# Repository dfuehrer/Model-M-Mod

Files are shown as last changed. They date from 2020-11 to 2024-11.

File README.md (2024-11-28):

# keyboard
- Arduino sketch that works ok for windows and menu keys
    - they occasionally miss the release so I'll have to make the code better later
        - or give up and switch to qmk
- used kailh choc brown switches cause theyre low profile to sit on the plastic
    - maybe I should have used a clicky switch since it's not like the tactile switches match the buckling springs in any way
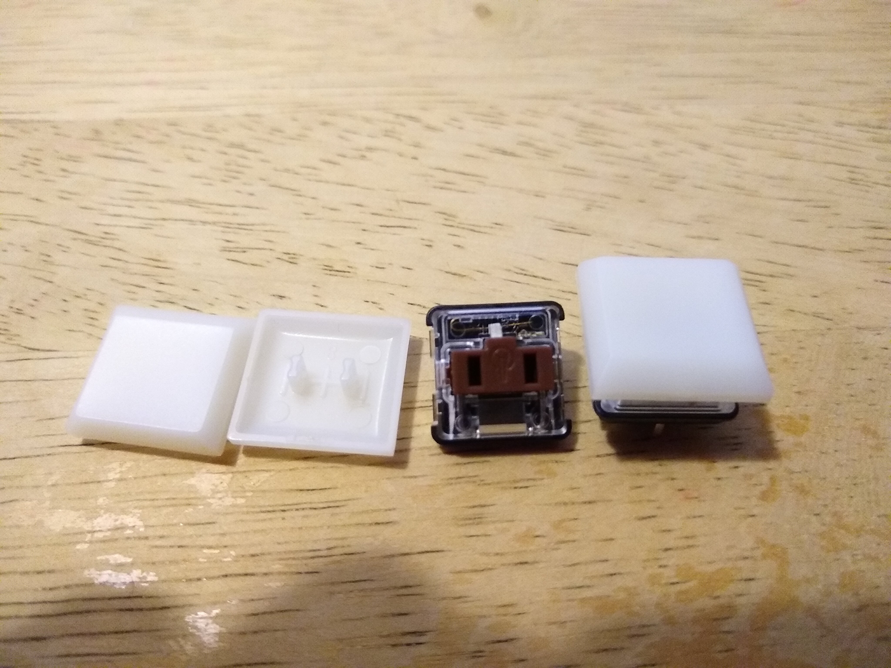
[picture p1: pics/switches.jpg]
Kailh choc brown switches


## procedure
- first routed wires from around the backplate thingy so they come up out the top to the left of each missing key area
    - I used some speaker wire which was convenient because it kept the wires together and organized
    - hot glued the wires in place on the inner back board
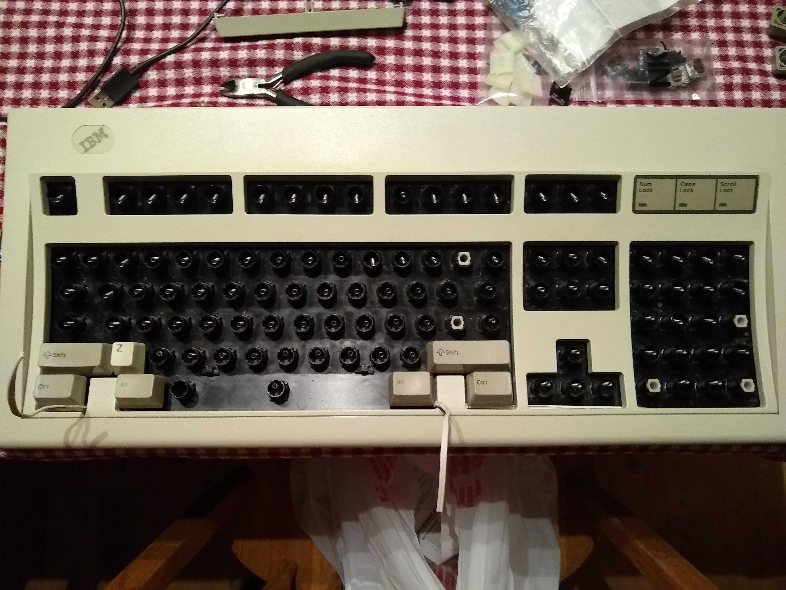
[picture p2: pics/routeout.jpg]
route wire out

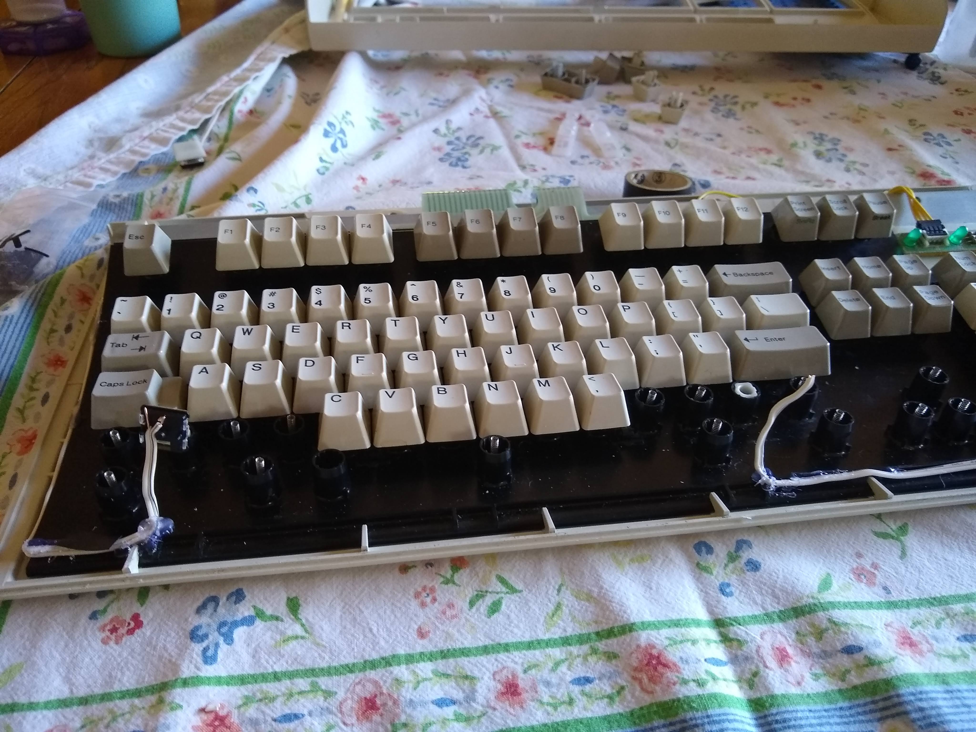
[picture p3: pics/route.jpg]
route on board

- measured the distance needed for the keyswitches and cut the wire to length
    - the wire comes out the corner towards the front left and turns up to the switches on the key
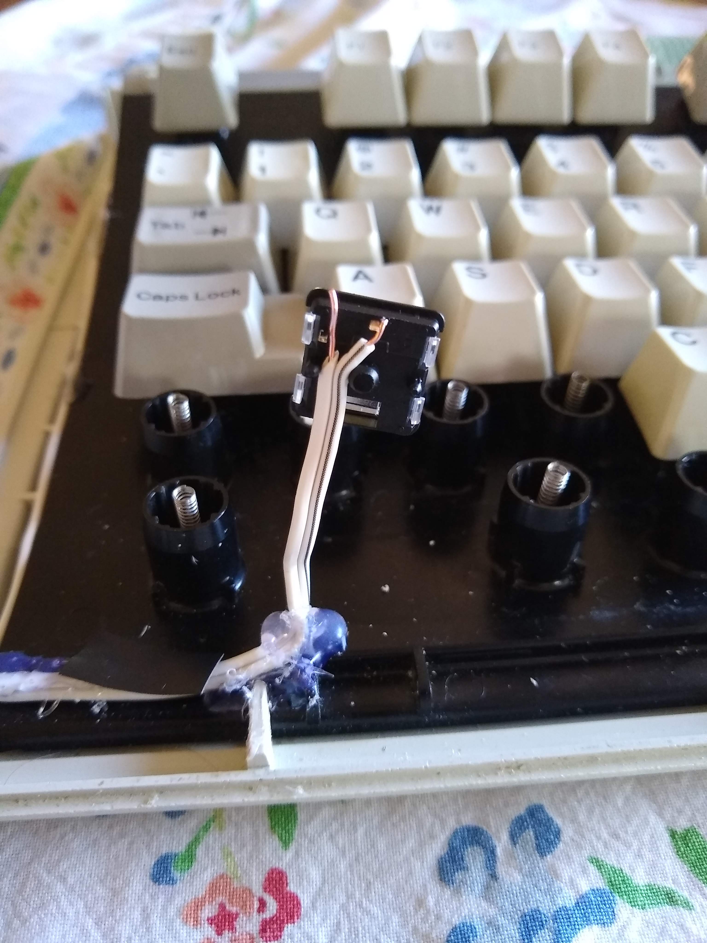
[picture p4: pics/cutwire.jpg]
cut wires to length

- soldered the wires to the switches
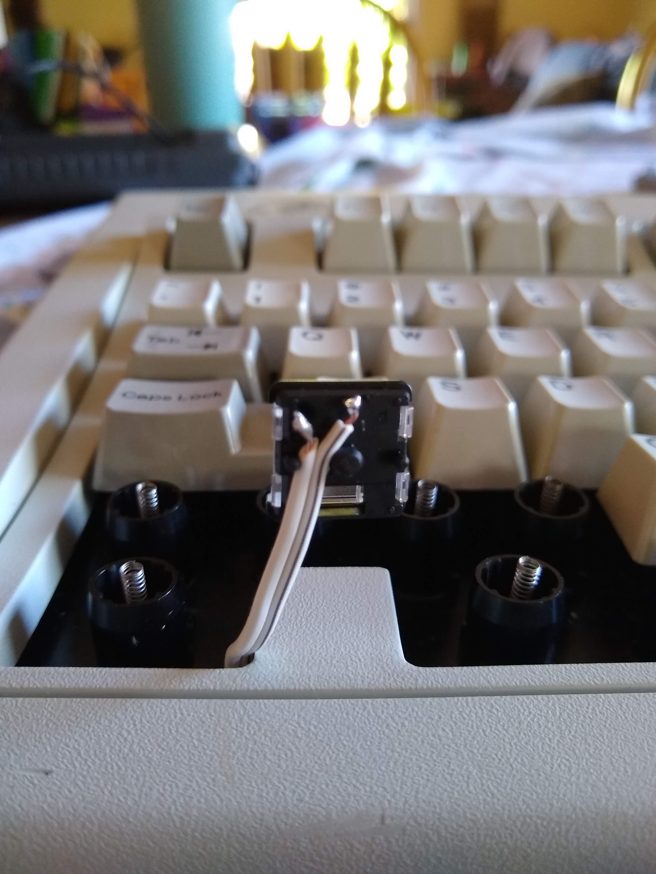
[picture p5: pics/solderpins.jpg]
soldered switch pins to wire

- pulled the wires through on the back, staying out of the way of supports
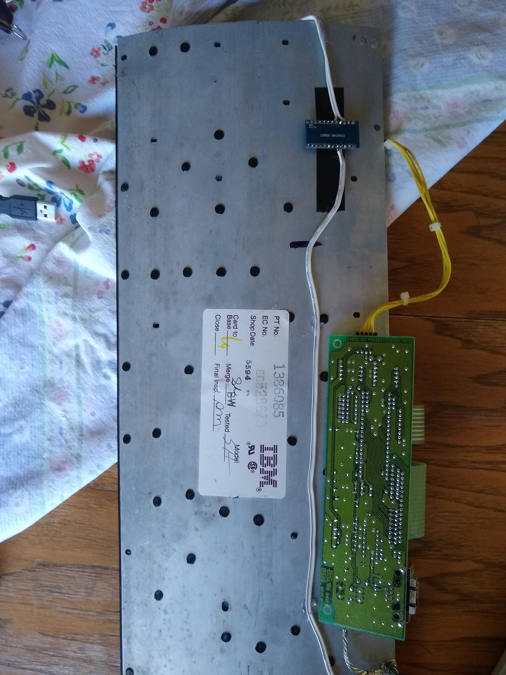
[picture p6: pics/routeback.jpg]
route wires on back of board

- met the wires together over the hole thingy that looks like its for a speaker or something
- cut the wires to length to fit in the arduino
    - accidentally did this upside down
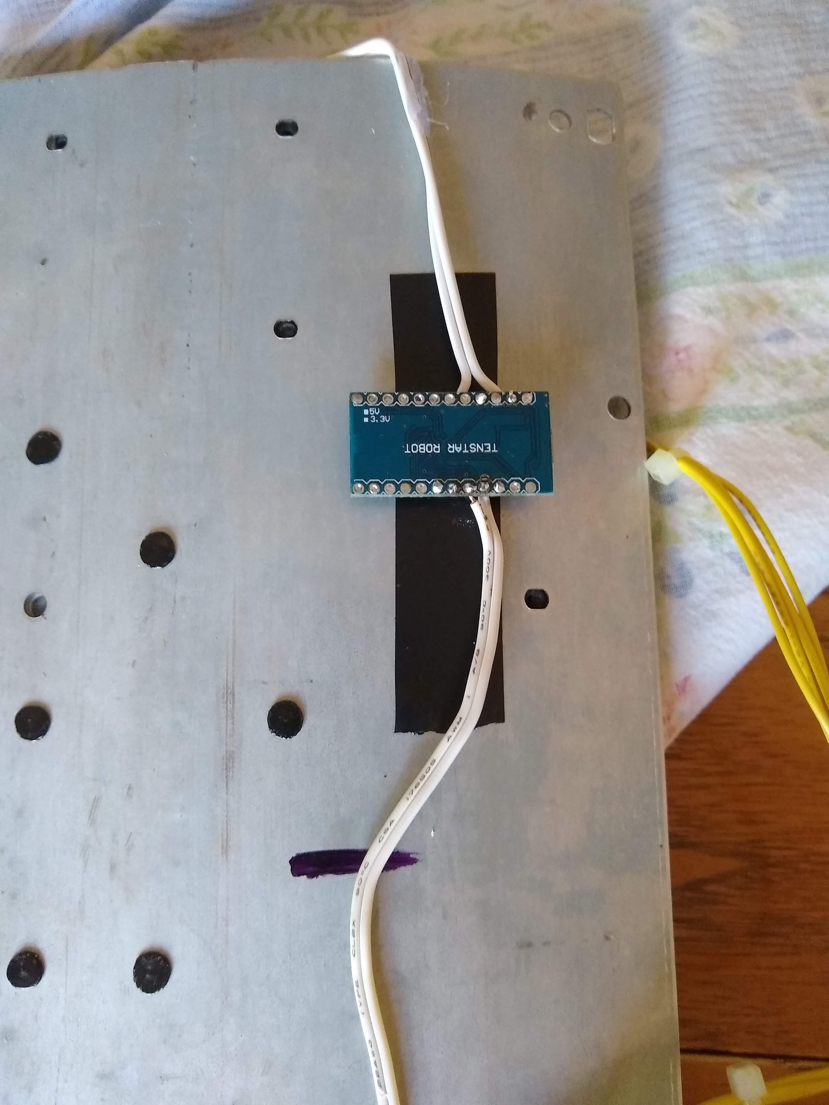
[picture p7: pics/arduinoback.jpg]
put wires in arduino

- soldered the wires into the correct pins
    - here I used pins 2 and 3 becuase they are interrupt pins and then connected the other pins to gnd
- cut a usb cable in half beyond the distance I needed to fit it in the keyboard
- my usb port was facing towards the back so I looped it 360° to go through the slots
    - in my case the usb wires bunched into a square fit perfectly through
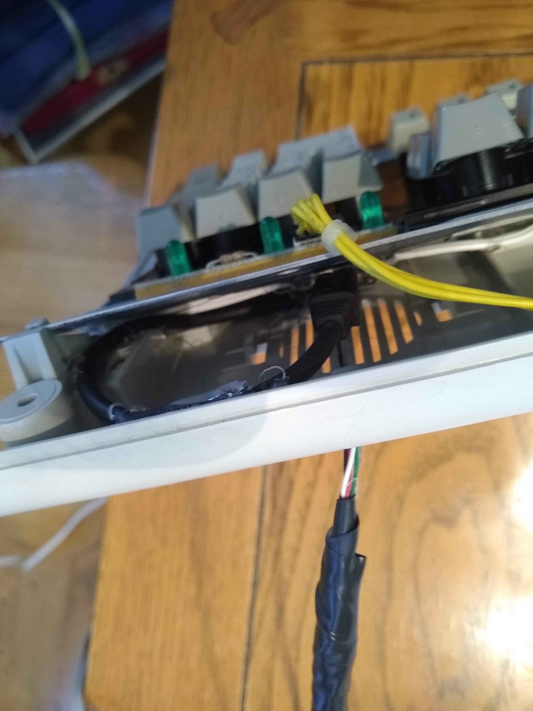
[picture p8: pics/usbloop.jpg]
usb cable loop through and out slots

- solder the usb wires back together and jankily electrical tape it cause you didn't buy heat shrink
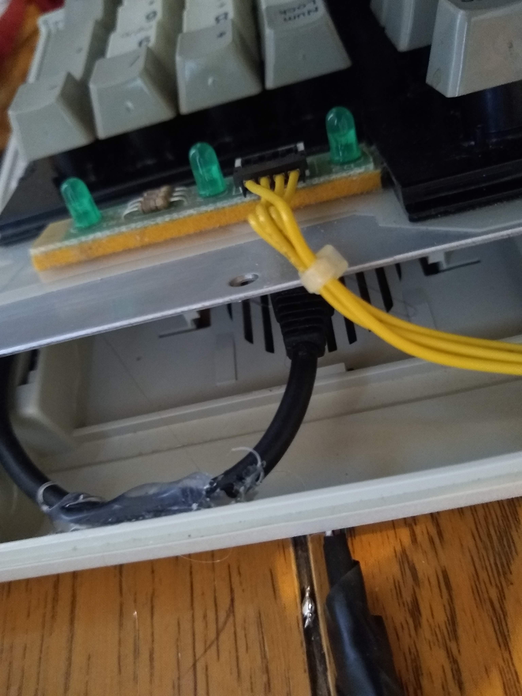
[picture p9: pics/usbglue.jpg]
glued usb cable in

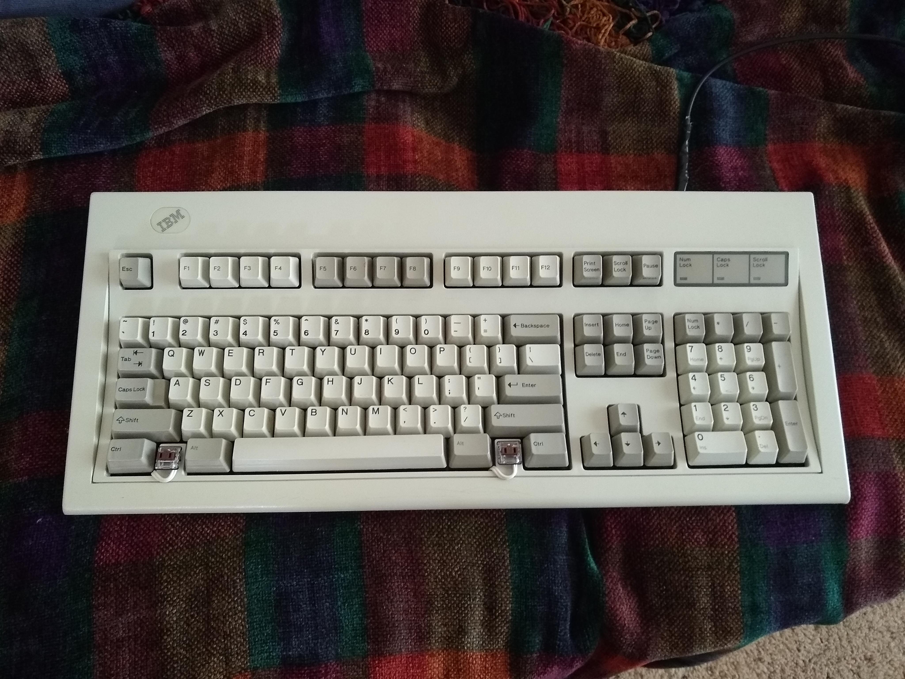
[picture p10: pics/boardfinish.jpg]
finished board

- the 3-D model here supports the keyswitches so they don't wobble since they were designed to be inserted in something
    - this model leaves just enough room for the wires go go through the gap between the pegs on the side with the pins so it works alright
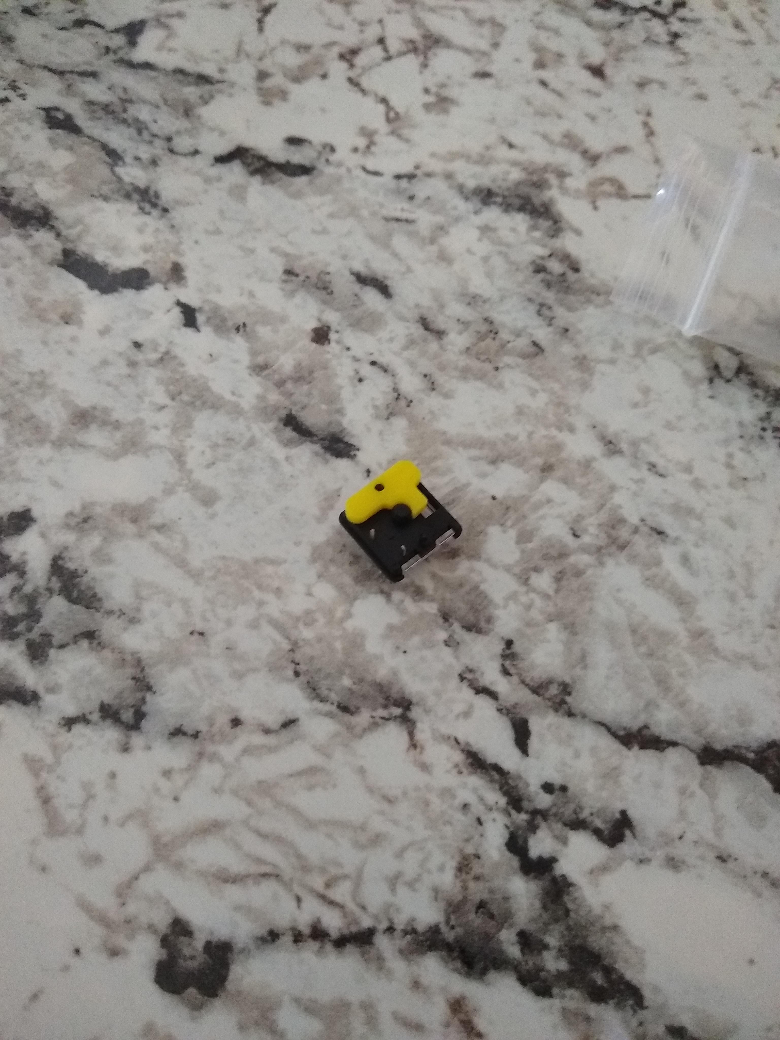
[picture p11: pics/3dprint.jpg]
3d print on keyswitch

- at this point I just hot glue the switches on top after making sure the wires don't interfere with the keys next to it
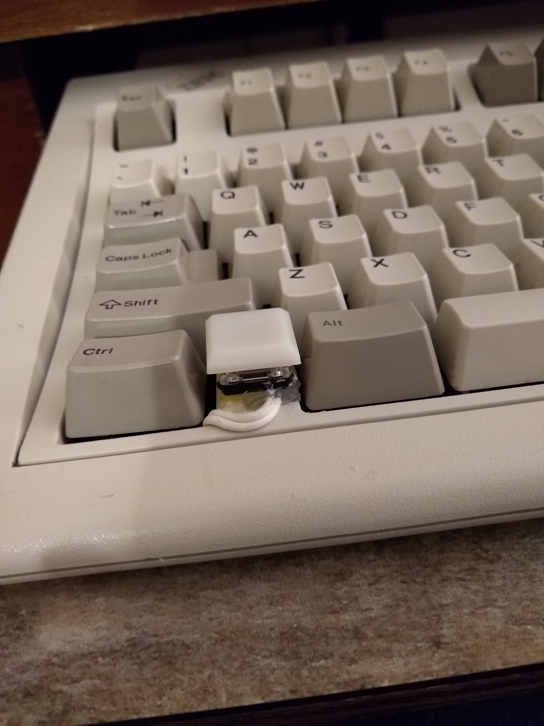
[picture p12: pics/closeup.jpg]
close up of finished switch

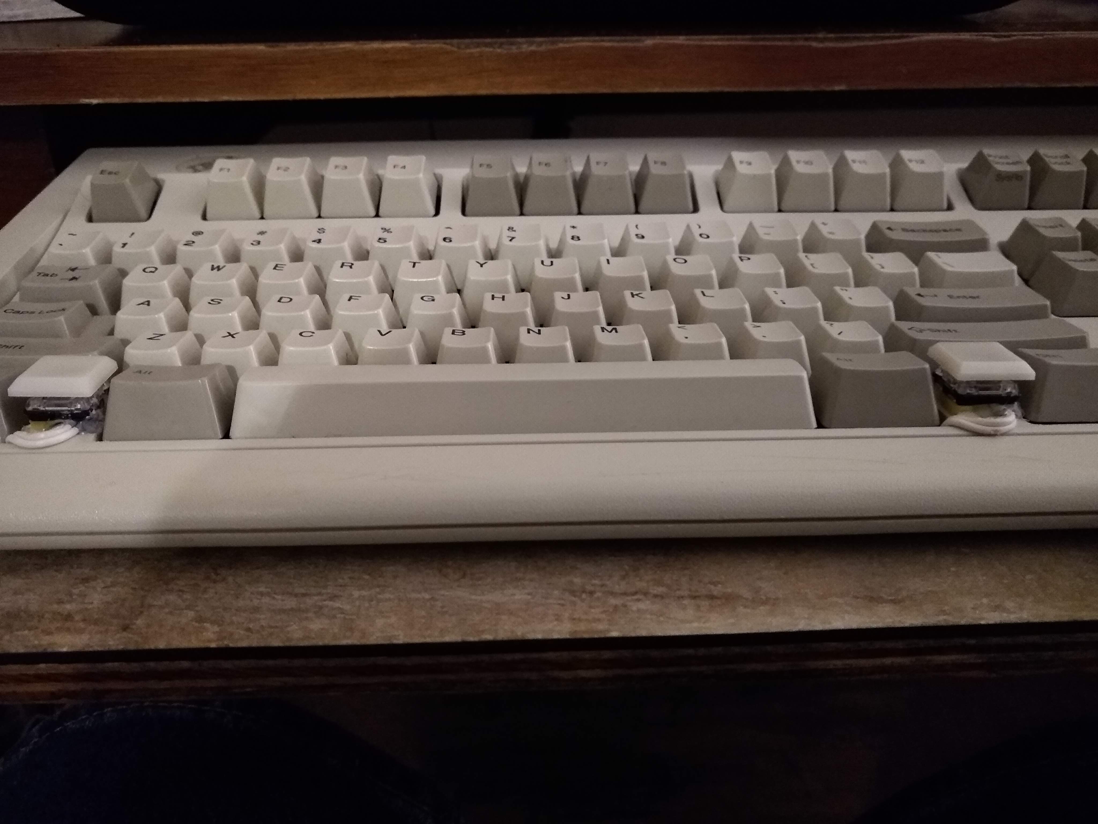
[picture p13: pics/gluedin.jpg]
finished switches


### Next
- I need to figure out painting or somethinging logos on the keyswitches
    - definitely want a Tux the Linux penguin one
    - a windows 2.0 logo would be interesting cuase the era is roughly right, it was able to run on the ps/2
        - I guess unicomp made the model M with a windows key that looks like windows 3 or 95 something
    - maybe the ibm ps/2 logo since this was used for the ibm ps/2
        - os/2 I guess is the os it ran
- upgrade to [M-Star](https://gitlab.com/esr/m-star)

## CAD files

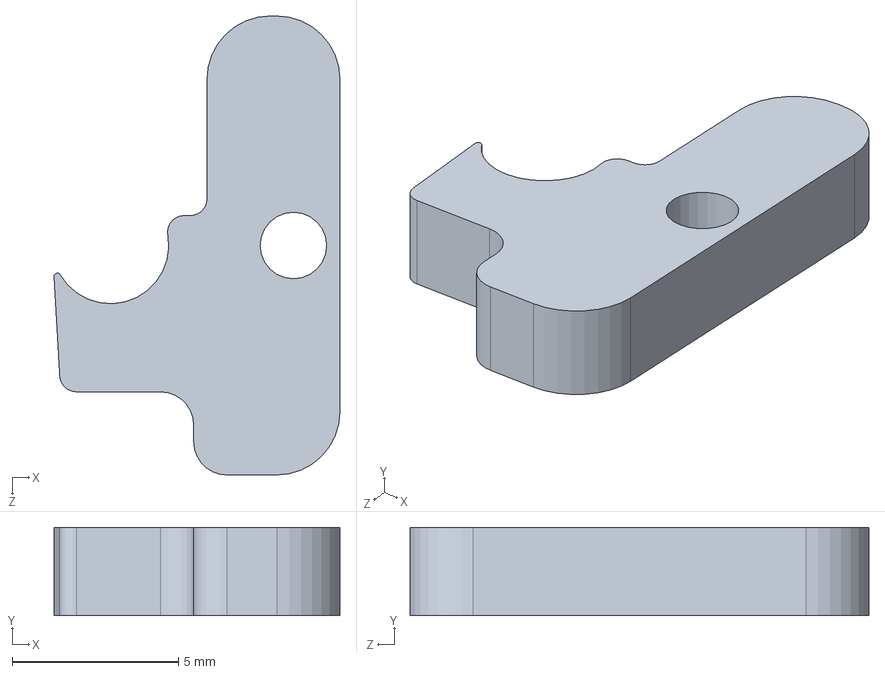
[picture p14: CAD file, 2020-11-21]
3d/orig/switchholder.SLDPRT
8.60 x 2.65 x 13.8 mm

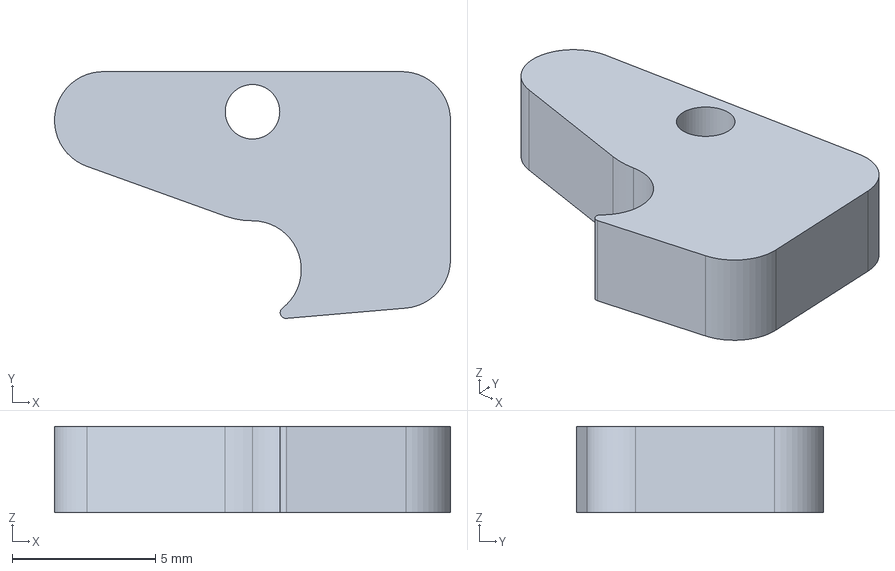
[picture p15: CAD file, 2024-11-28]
3d/switchholder.FCStd
13.8 x 8.60 x 3.00 mm

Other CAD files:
3d/switchholder-Body.step
3d/orig/switchholder.STL

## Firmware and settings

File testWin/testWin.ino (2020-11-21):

#include "Keyboard.h"

#define KEY_MENU 0xED
#define SPACING_TIME 1000

const int winPin = 2;
const int optPin = 3;
volatile bool winPressed = false;
volatile bool optPressed = false;
volatile uint32_t winPtime;
volatile uint32_t optPtime;
uint32_t curTime;

void pressWin();
void pressOpt();

void setup() {
    // make pin 2 an input and turn on the pull-up resistor so it goes high unless
    // connected to ground:
    pinMode(winPin, INPUT_PULLUP);
    pinMode(optPin, INPUT_PULLUP);
    attachInterrupt(digitalPinToInterrupt(winPin), pressWin,   CHANGE);
    attachInterrupt(digitalPinToInterrupt(optPin), pressOpt,   CHANGE);
    // initialize control over the keyboard:
    Keyboard.begin();
    curTime = winPtime = optPtime = micros();
}

void loop() {
    curTime = micros();
    if(winPressed && curTime > winPtime + SPACING_TIME){
        Serial.println(curTime - winPtime);
        if(digitalRead(winPin) == LOW){
            Keyboard.press(KEY_LEFT_GUI);
        }else{
            Keyboard.release(KEY_LEFT_GUI);
        }
        winPressed = false;
    }

    if(optPressed && curTime > optPtime + SPACING_TIME){
        Serial.println(curTime - optPtime);
        if(digitalRead(optPin) == LOW){
            Keyboard.press(KEY_MENU);
        }else{
            Keyboard.release(KEY_MENU);
        }
        optPressed = false;
    }

    yield();
}

void pressWin(){
    winPressed = true;
    winPtime = micros();
}
void pressOpt(){
    optPressed = true;
    optPtime = micros();
}

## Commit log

2020-11-21 First commit with arduino keyboard code, 3d model, and readme
    [switchholder.SLDPRT, switchholder.STL]
2024-11-28 moved 3d files to new 3d directory for organization
    [switchholder.SLDPRT, switchholder.STL]
2024-11-28 recreated switch holder in FreeCAD, moved original to orig directory
    [switchholder-Body.step, switchholder.FCStd, switchholder.SLDPRT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]
